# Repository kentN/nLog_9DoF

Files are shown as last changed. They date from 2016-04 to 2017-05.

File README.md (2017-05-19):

# nLog_9DoF #
Arduino compatible embedded microSD data logger





----------

## Features ##

- 5V and 3.3V Regurator
- ATmega644P (4kB RAM 64kB ROM) 5V 16MHz 
- Size and pin pitch compatible with UP-204GSR Universal PCB
- microSD hinge socket 
- MPU-9250
- RX8900 RealTime Clock (TCXO) (Backup Battery Option)
- 3.3V I2C bus, 5V UART,SPI, ADC/GPIO 

----------
## PIN Map ##


- VIN has Reverse current protection

----------

## Applications ##

- analog & Motion Datalogger

----------

## Project Environment ##

- KiCad (4.0.1)
- Arduino 1.0.6
- Sanguino bootloader
- SDfatlib

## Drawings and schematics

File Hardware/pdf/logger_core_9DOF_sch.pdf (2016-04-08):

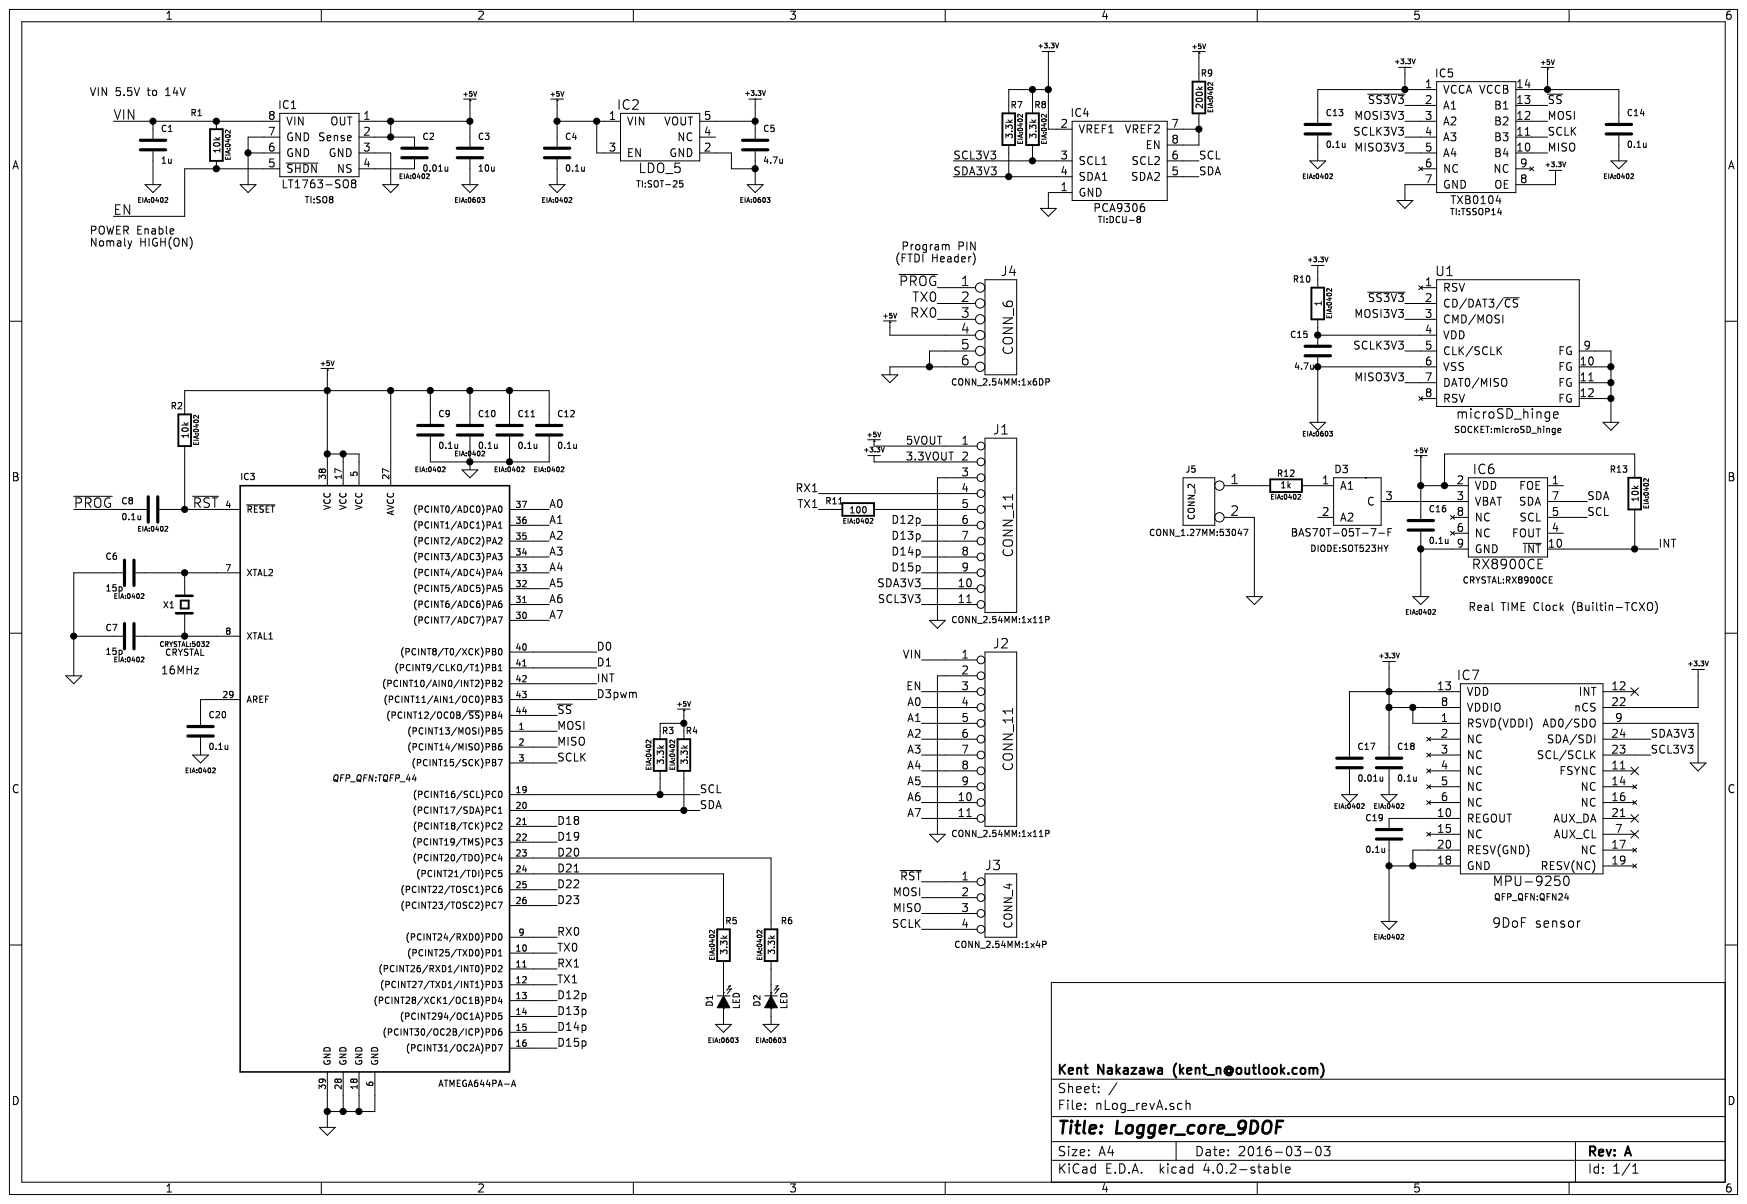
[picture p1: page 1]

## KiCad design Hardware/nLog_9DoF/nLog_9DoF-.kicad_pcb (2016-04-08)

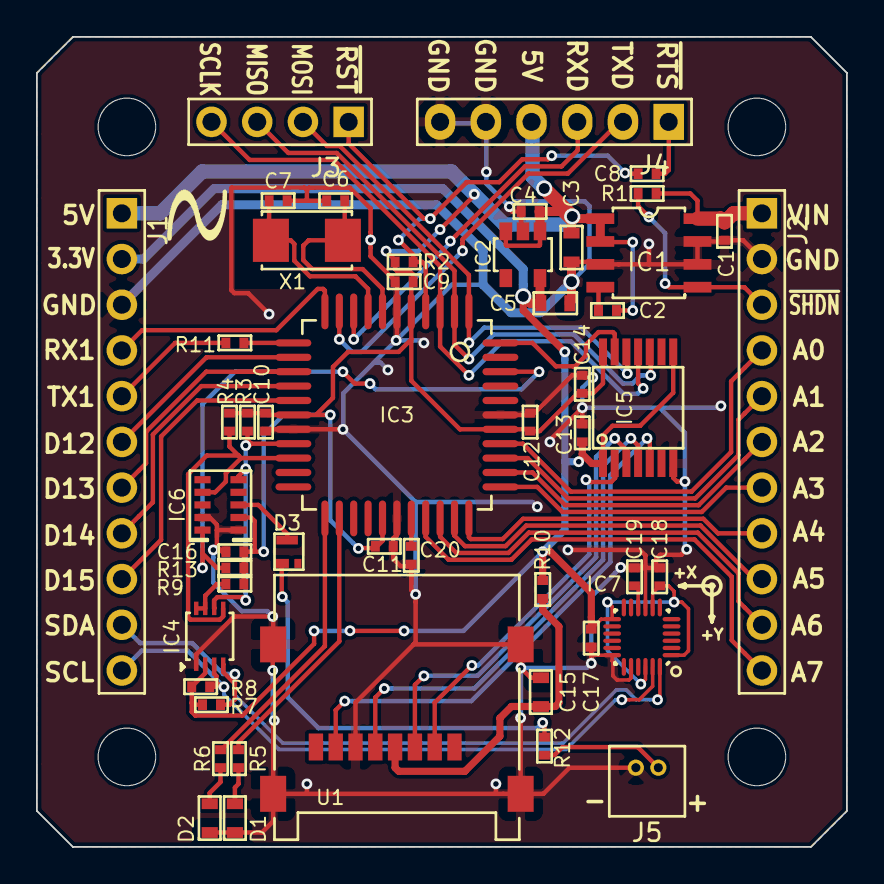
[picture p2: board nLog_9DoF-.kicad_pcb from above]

Board: 2 copper layers, 45.0 x 45.0 mm, 54 parts (0 on the bottom side), 51 nets.

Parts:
C1: 1u; 0402
C2, C17: 0.01u; 0402
C3: 10u; 0603
C4, C8, C9, C10, C11, C12, C13, C14, C16, C18, C19, C20: 0.1u; 0402
C5, C15: 4.7u; 0603
C6, C7: 15p; 0402
D1, D2: LED; 0603
D3: BAS70T-05T-7-F; SOT523HY
Drill_M3, Drill_M3#2, Drill_M3#3, Drill_M3#4: H**; drill_M3
IC1: LT1763-SO8; SO8
IC2: LDO_5; SOT-25
IC3: ATMEGA644PA-A; TQFP_44
IC4: PCA9306; DCU-8
IC5: TXB0104; TSSOP14
IC6: RX8900CE
IC7: MPU-9250; QFN24
J1, J2: CONN_11; 1x11P
J3: CONN_4; 1x4P
J4: CONN_6; 1x6DP
J5: CONN_2; DF13-2P
R1, R2, R13: 10k; 0402
R3, R4, R5, R6, R7, R8: 3.3k; 0402
R9: 200k; 0402
R10: 1; 0402
R11: 100; 0402
R12: 1k; 0402
U1: microSD_hinge
X1: CRYSTAL; 5032

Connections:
+3.3V: C5.1, C13.1, C17.1, C18.1, IC2.5, IC4.2, IC5.1, IC5.8, IC7.1, IC7.8, IC7.13, IC7.22, J1.2, R7.1, R8.1, R10.1
+5V: C2.1, C3.1, C4.1, C9.1, C10.1, C11.1, C12.1, C14.1, C16.1, IC1.1, IC1.2, IC2.1, IC2.3, IC3.5, IC3.17, IC3.27, IC3.38, IC5.14, IC6.2, J1.1, J4.4, R2.1, R3.1, R4.1, R9.1, R13.1
/A0: IC3.37, J2.4
/A1: IC3.36, J2.5
/A2: IC3.35, J2.6
/A3: IC3.34, J2.7
/A4: IC3.33, J2.8
/A5: IC3.32, J2.9
/A6: IC3.31, J2.10
/A7: IC3.30, J2.11
/D12p: IC3.13, J1.6
/D13p: IC3.14, J1.7
/D14p: IC3.15, J1.8
/D15p: IC3.16, J1.9
/D20: IC3.23, R6.1
/D21: IC3.24, R5.1
/EN: IC1.5, J2.3, R1.2
/INT: IC3.42, IC6.10, R13.2
/MISO: IC3.2, IC5.10, J3.3
/MISO3V3: IC5.5, U1.7
/MOSI: IC3.1, IC5.12, J3.2
/MOSI3V3: IC5.3, U1.3
/RX0: IC3.9, J4.3
/RX1: IC3.11, J1.4
/SCL: IC3.19, IC4.6, IC6.5, R3.2
/SCL3V3: IC4.3, IC7.23, J1.11, R8.2
/SCLK: IC3.3, IC5.11, J3.4
/SCLK3V3: IC5.4, U1.5
/SDA: IC3.20, IC4.5, IC6.7, R4.2
/SDA3V3: IC4.4, IC7.24, J1.10, R7.2
/TX0: IC3.10, J4.2
/TX1: IC3.12, R11.2
/VIN: C1.1, IC1.8, J2.1, R1.1
/~PROG: C8.2, J4.1
/~RST: C8.1, IC3.4, J3.1, R2.2
/~SS: IC3.44, IC5.13
/~SS3V3: IC5.2, U1.2
GND: C1.2, C3.2, C4.2, C5.2, C6.2, C7.2, C9.2, C10.2, C11.2, C12.2, C13.2, C14.2, C15.2, C16.2, C17.2, C18.2, C19.2, C20.2, D1.1, D2.1, IC1.3, IC1.6, IC1.7, IC2.2, IC3.6, IC3.18, IC3.28, IC3.39, IC4.1, IC5.7, IC6.1, IC6.9, IC7.9, IC7.18, IC7.20, J1.3, J2.2, J4.5, J4.6, J5.2, U1.6, U1.9, U1.10, U1.11, U1.12
unnamed: C2.2, IC1.4
unnamed: C6.1, IC3.7, X1.2
unnamed: C7.1, IC3.8, X1.1
unnamed: C15.1, R10.2, U1.4
unnamed: C19.1, IC7.10
unnamed: C20.1, IC3.29
unnamed: D1.2, R5.2
unnamed: D2.2, R6.2
unnamed: D3.1, R12.2
unnamed: D3.3, IC6.3
unnamed: IC4.7, IC4.8, R9.2
unnamed: J1.5, R11.1
unnamed: J5.1, R12.1
